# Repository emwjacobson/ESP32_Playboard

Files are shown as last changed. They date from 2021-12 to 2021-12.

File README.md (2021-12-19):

# ESP32 Playboard

I wasn't sure what to call this project other than the Playboard, so that's what it is. I got really into Espressif's [ESP-IDF](https://idf.espressif.com/) for developing on the ESP32, a dual core system running at 240MHz. The module that I chose has a 16MB SPI Flash chip and 8MB of PSRAM. 8MB and 4MB variants of the WROVER kit are also available, which can slightly reduce the price of it.

Using the LCSC BOM tool, a single board will cost ~$12, reducing to ~$8/board if making 100.

The Playboard includes the following sensors/devices:
- IR LED for Transmitting
- IR Receiver
- MicroSD Card Slot
- MPU-6050 IMU
- SHT30 Temperature/Humidity Sensor

In the PCB I added a small notch between the IR LED and the IR Receiver. This can be used to add a little divider to seperate them if simultaneous operation is required. Without a divider, the LED will be detected by the receiver.

## Schematic

Click to view full size PDF of schematic.
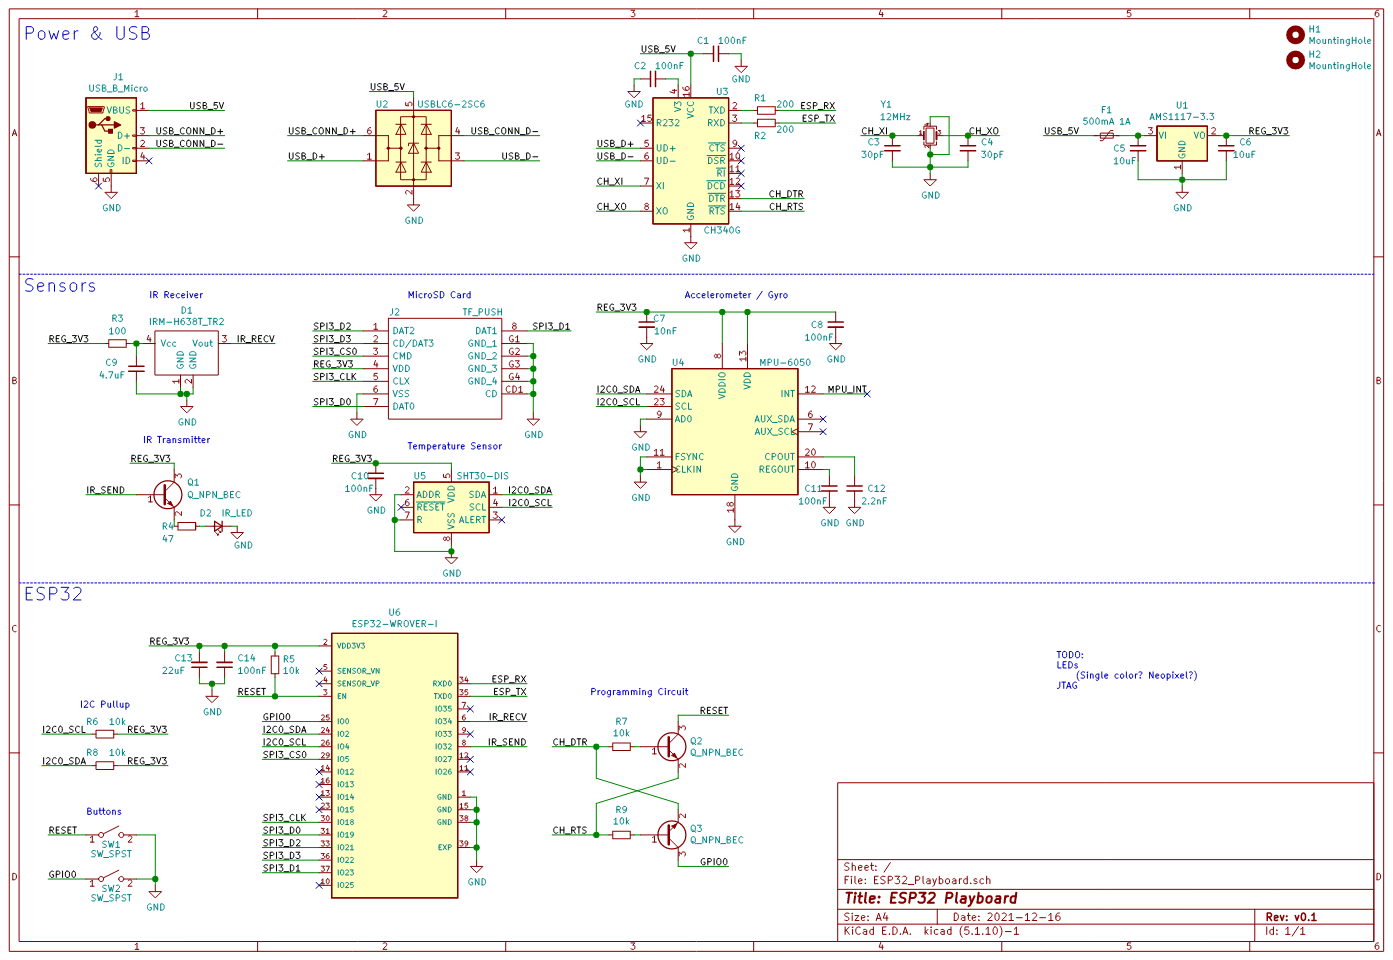
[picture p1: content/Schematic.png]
Schematic


## PCB

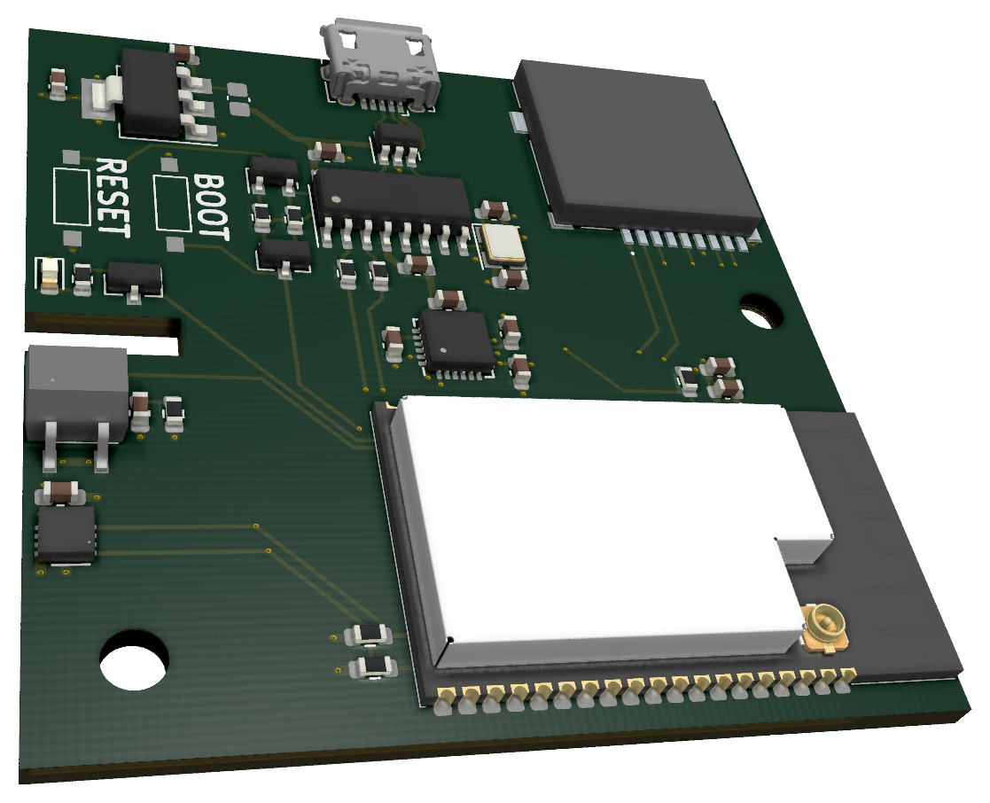
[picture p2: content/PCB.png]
PCB


## TODO

- JTAG Header
- Add some GPIO LEDs!
- Fill out the README more!

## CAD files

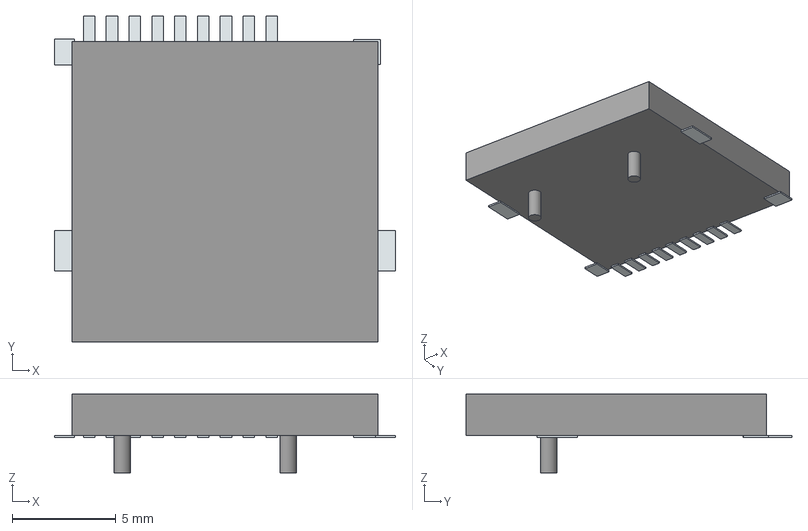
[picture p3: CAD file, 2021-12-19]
models/TF_PUSH.stp
16.5 x 15.7 x 3.80 mm
Pins
Lugs x 2

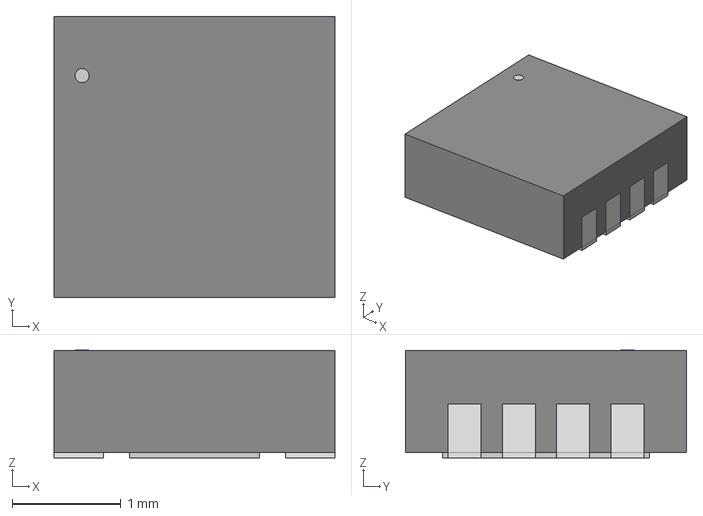
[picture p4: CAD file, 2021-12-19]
models/SHT3x-DIS_SEN.step
2.59 x 2.59 x 0.993 mm

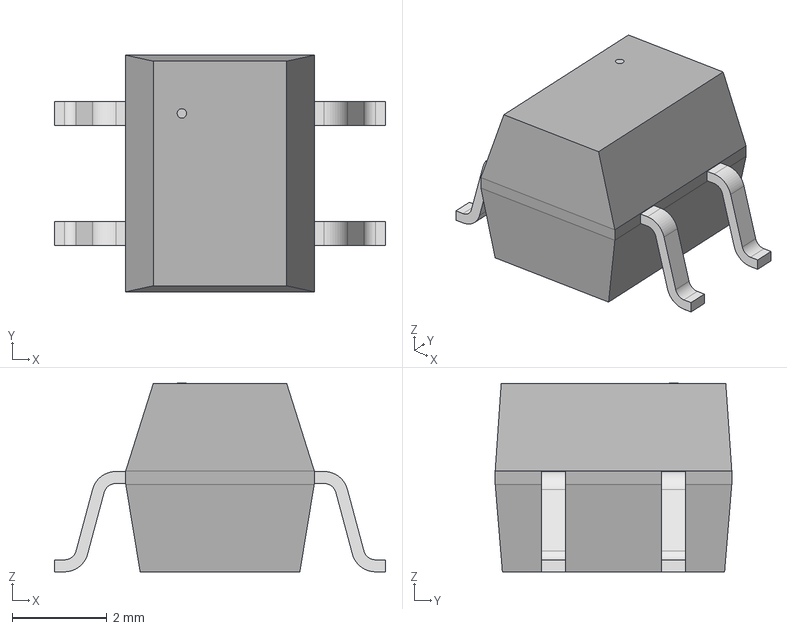
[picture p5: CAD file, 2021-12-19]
models/IRM-H638TTR2.step
7.00 x 5.00 x 3.99 mm

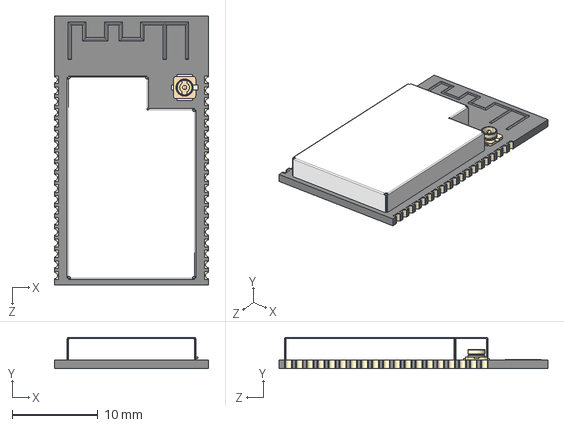
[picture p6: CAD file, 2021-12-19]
models/ESP32-WROVER-I.step
18.0 x 3.65 x 31.4 mm

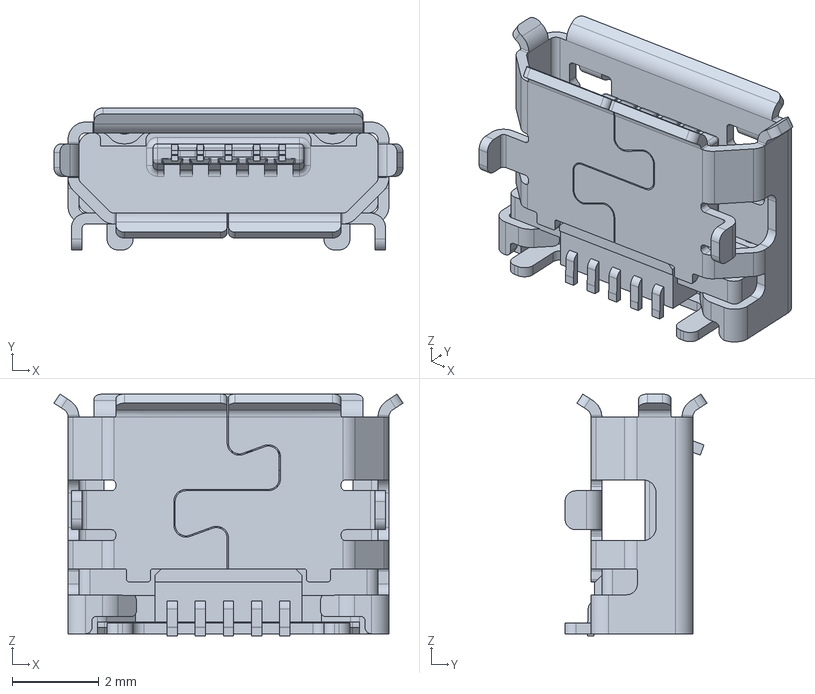
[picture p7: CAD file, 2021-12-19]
models/10118194-0001LF.STEP
8.05 x 3.27 x 5.58 mm

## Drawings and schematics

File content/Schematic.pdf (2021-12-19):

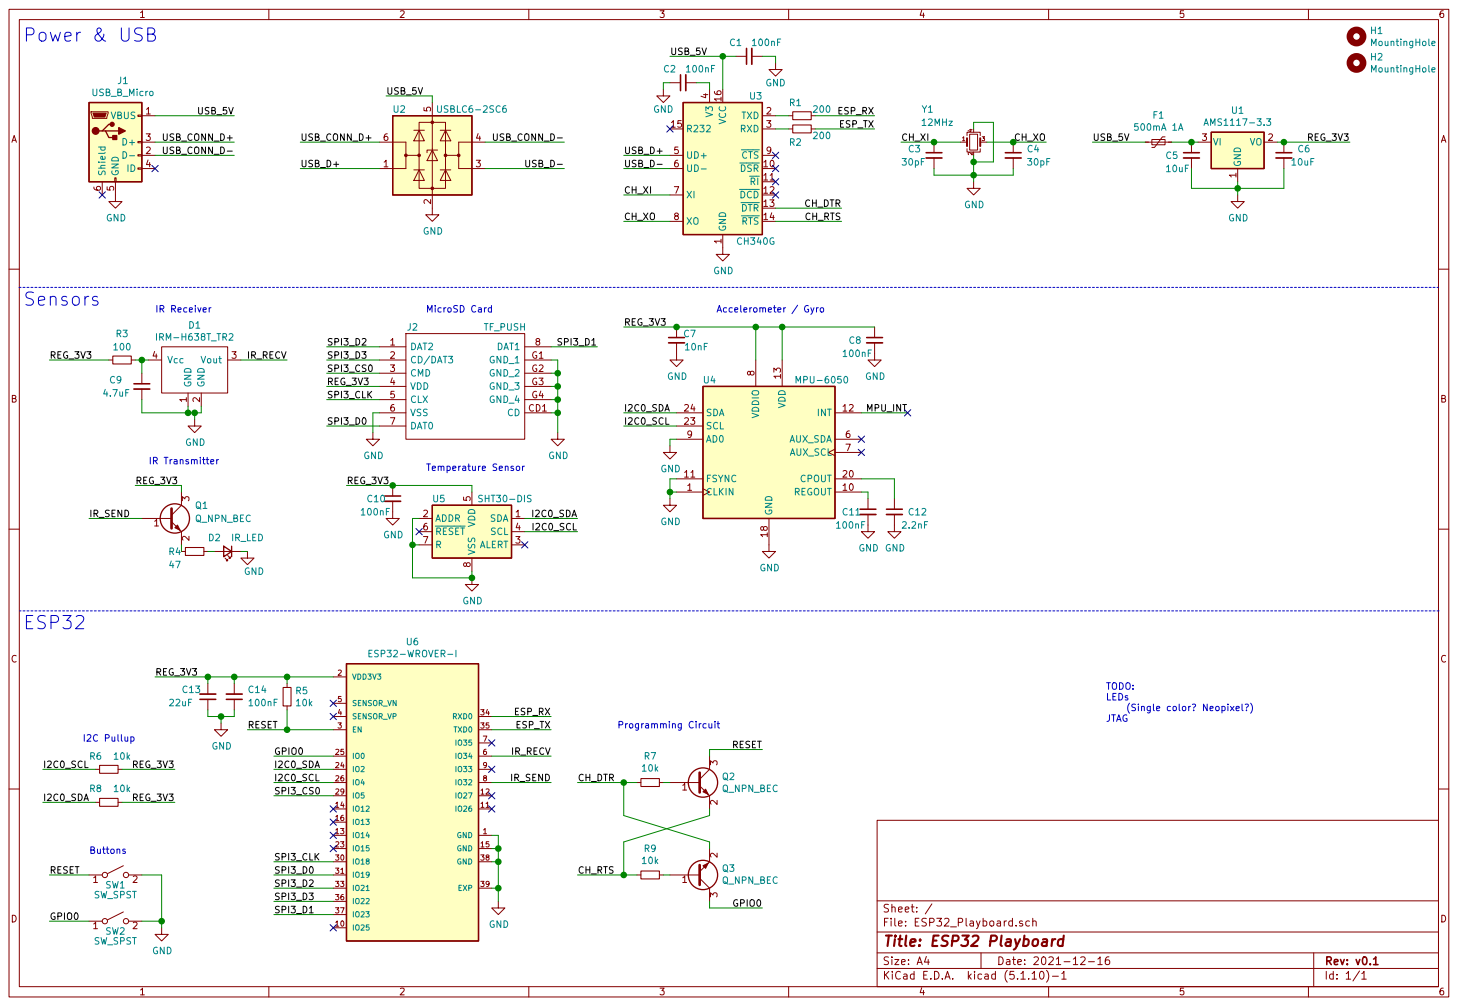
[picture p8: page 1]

1 DSR 10 RI 11 DCD 12 DTR 13 RTS 14 R232 15 VCC 16 TXD 2 RXD 3 V3

4 UD+ 5 UD- 6 XI 7 XO 8 CTS 9 U3 CH340G

1 VO 2 VI 3 U1 AMS1117-3.3 GND GND

(Single color? Neopixel?) JTAG

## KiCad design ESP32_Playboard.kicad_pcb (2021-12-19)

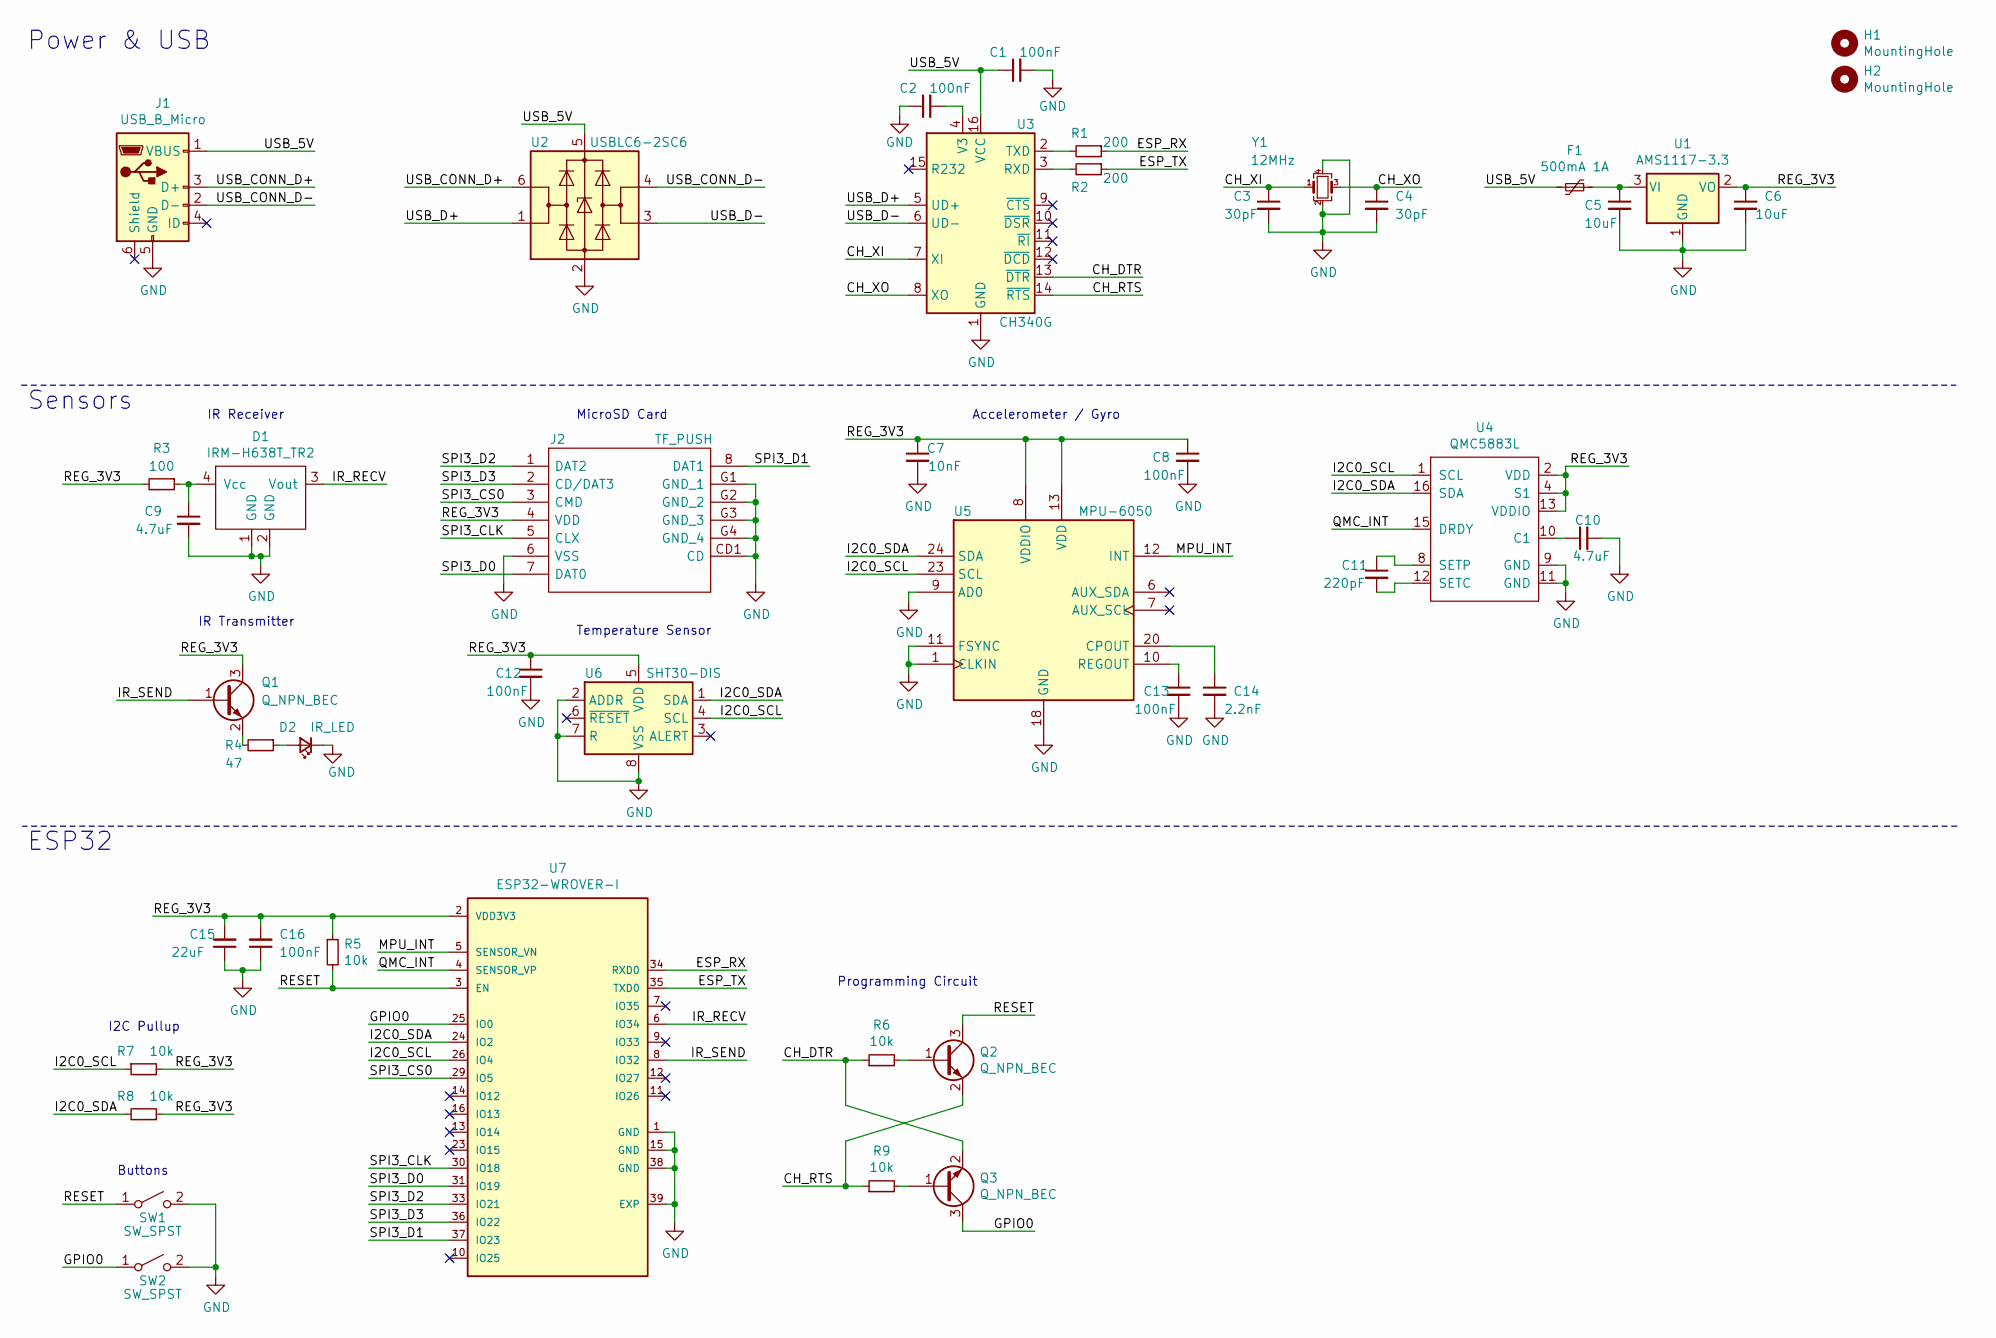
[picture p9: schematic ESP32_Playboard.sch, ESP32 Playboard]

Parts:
C1, C2, C8, C12, C13, C16: 100nF; C_0603_1608Metric; Manufacturer Part Number CC0603KRX7R9BB104; LCSC Part Number C14663
C3, C4: 30pF; C_0603_1608Metric; Manufacturer Part Number CC0603FRNPO9BN200; LCSC Part Number C326779
C5, C6: 10uF; C_0603_1608Metric; Manufacturer Part Number CL10A106KP8NNNC; LCSC Part Number C19702
C7: 10nF; C_0603_1608Metric; Manufacturer Part Number 0603B103K500NT; LCSC Part Number C57112
C9, C10: 4.7uF; C_0603_1608Metric; Manufacturer Part Number CL10A475KQ8NNNC; LCSC Part Number C8032
C11: 220pF; C_0603_1608Metric; Manufacturer Part Number CL10C221JB8NNNC; LCSC Part Number C27675
C14: 2.2nF; C_0603_1608Metric; Manufacturer Part Number 0603B222K500NT; LCSC Part Number C1604
C15: 22uF; C_0603_1608Metric; Manufacturer Part Number CL10A226MQ8NRNC; LCSC Part Number C59461
D1: IRM-H638T_TR2; LED-SMD-4; Manufacturer Part Number IRM-H638T/TR2; LCSC Part Number C91447
D2: IR_LED; LED_0603_1608Metric; Manufacturer Part Number MIR60363T; LCSC Part Number C50494
F1: 500mA 1A; Fuse_0805_2012Metric_Castellated; Manufacturer Part Number BSMD0805-050-24V; LCSC Part Number C910822
H1, H2: MountingHole; MountingHole_3.2mm_M3
J1: USB_B_Micro; USB_Micro-B_Amphenol_10118194_Horizontal; Manufacturer Part Number 10118194-0001LF; LCSC Part Number C132563
J2: TF_PUSH; TFPUSH; Manufacturer Part Number TF PUSH; LCSC Part Number C393941
Q1, Q2, Q3: Q_NPN_BEC; SOT-23; Manufacturer Part Number PMBT3904,215; LCSC Part Number C8667
R1, R2: 200; R_0603_1608Metric; Manufacturer Part Number 0603WAJ0201T5E; LCSC Part Number C25217
R3: 100; R_0603_1608Metric; Manufacturer Part Number RC0603FR-07100RL; LCSC Part Number C105588
R4: 47; R_0603_1608Metric; Manufacturer Part Number 0603WAJ0470T5E; LCSC Part Number C1211
R5, R6, R7, R8, R9: 10k; R_0603_1608Metric; Manufacturer Part Number 0603WAF1002T5E; LCSC Part Number C25804
SW1, SW2: SW_SPST; TS-1101-C-W; Manufacturer Part Number TS-1101-C-W; LCSC Part Number C318938
U1: AMS1117-3.3; SOT-223-3_TabPin2; Manufacturer Part Number AMS1117-3.3; LCSC Part Number C347222
U2: USBLC6-2SC6; SOT-23-6; Manufacturer Part Number USBLC6-2SC6; LCSC Part Number C2827654
U3: CH340G; SOIC-16_3.9x9.9mm_P1.27mm; Manufacturer Part Number CH340G; LCSC Part Number C14267
U4: QMC5883L; LGA-16_3x3mm_P0.5mm; Manufacturer Part Number QMC5883L; LCSC Part Number C976032
U5: MPU-6050; InvenSense_QFN-24_4x4mm_P0.5mm; Manufacturer Part Number MPU-6050; LCSC Part Number C24112
U6: SHT30-DIS; Sensirion_DFN-8-1EP_2.5x2.5mm_P0.5mm_EP1.1x1.7mm; Manufacturer Part Number SHT30-DIS-B2.5KS; LCSC Part Number C77361
U7: ESP32-WROVER-I; XCVR_ESP32-WROVER-I; Manufacturer Part Number ESP32-WROVER-IE(16MB); LCSC Part Number C701352
Y1: 12MHz; Crystal_SMD_3225-4Pin_3.2x2.5mm; Manufacturer Part Number X322512MSB4SI; LCSC Part Number C9002

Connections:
/CH_DTR: Q3.2 (E), R6.1, U3.13 (~DTR)
/CH_RTS: Q2.2 (E), R9.1, U3.14 (~RTS)
/CH_XI: C3.1, U3.7 (XI), Y1.1
/CH_XO: C4.1, U3.8 (XO), Y1.3
/ESP_RX: R1.1, U7.34 (RXD0)
/ESP_TX: R2.1, U7.35 (TXD0)
/GPIO0: Q3.3 (C), SW2.1 (A), U7.25 (IO0)
/I2C0_SCL: R7.1, U4.1 (SCL), U5.23 (SCL), U6.4 (SCL), U7.26 (IO4)
/I2C0_SDA: R8.2, U4.16 (SDA), U5.24 (SDA), U6.1 (SDA), U7.24 (IO2)
/IR_RECV: D1.3 (Vout), U7.6 (IO34)
/IR_SEND: Q1.1 (B), U7.8 (IO32)
/MPU_INT: U5.12 (INT), U7.5 (SENSOR_VN)
/QMC_INT: U4.15 (DRDY), U7.4 (SENSOR_VP)
/REG_3V3: C6.1, C7.1, C8.1, C12.1, C15.2, C16.2, J2.4 (VDD), Q1.3 (C), R3.2, R5.1, R7.2, R8.1, U1.2 (VO), U4.2 (VDD), U4.4 (S1), U4.13 (VDDIO), U5.8 (VDDIO), U5.13 (VDD), U6.5 (VDD), U7.2 (VDD3V3)
/RESET: Q2.3 (C), R5.2, SW1.1 (A), U7.3 (EN)
/SPI3_CLK: J2.5 (CLX), U7.30 (IO18)
/SPI3_CS0: J2.3 (CMD), U7.29 (IO5)
/SPI3_D0: J2.7 (DAT0), U7.31 (IO19)
/SPI3_D1: J2.8 (DAT1), U7.37 (IO23)
/SPI3_D2: J2.1 (DAT2), U7.33 (IO21)
/SPI3_D3: J2.2 (CD/DAT3), U7.36 (IO22)
/USB_5V: C1.1, F1.2, J1.1 (VBUS), U2.5 (VBUS), U3.16 (VCC)
/USB_CONN_D+: J1.3 (D+), U2.6 (I/O1)
/USB_CONN_D-: J1.2 (D-), U2.4 (I/O2)
/USB_D+: U2.1 (I/O1), U3.5 (UD+)
/USB_D-: U2.3 (I/O2), U3.6 (UD-)
GND: C1.2, C2.1, C3.2, C4.2, C5.2, C6.2, C7.2, C8.2, C9.2, C10.2, C12.2, C13.2, C14.2, C15.1, C16.1, D1.1 (GND), D1.2 (GND), D2.1 (K), J1.5 (GND), J2.6 (VSS), J2.CD1 (CD), J2.G1 (GND_1), J2.G2 (GND_2), J2.G3 (GND_3), J2.G4 (GND_4), SW1.2 (B), SW2.2 (B), U1.1 (GND), U2.2 (GND), U3.1 (GND), U4.9 (GND), U4.11 (GND), U5.1 (CLKIN), U5.9 (AD0), U5.11 (FSYNC), U5.18 (GND), U6.2 (ADDR), U6.7 (R), U6.8 (VSS), U6.9 (VSS), U7.1 (GND), U7.15 (GND), U7.38 (GND), U7.39 (EXP), Y1.2, Y1.4
unnamed: C2.2, U3.4 (V3)
unnamed: C5.1, F1.1, U1.3 (VI)
unnamed: C9.1, D1.4 (Vcc), R3.1
unnamed: C10.1, U4.10 (C1)
unnamed: C11.1, U4.8 (SETP)
unnamed: C11.2, U4.12 (SETC)
unnamed: C13.1, U5.10 (REGOUT)
unnamed: C14.1, U5.20 (CPOUT)
unnamed: D2.2 (A), R4.1
unnamed: Q1.2 (E), R4.2
unnamed: Q2.1 (B), R6.2
unnamed: Q3.1 (B), R9.2
unnamed: R1.2, U3.2 (TXD)
unnamed: R2.2, U3.3 (RXD)

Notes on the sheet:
Power & USB
ESP32
Sensors
IR Receiver
IR Transmitter
MicroSD Card
Temperature Sensor
Programming Circuit
I2C Pullup
Buttons
Accelerometer / Gyro

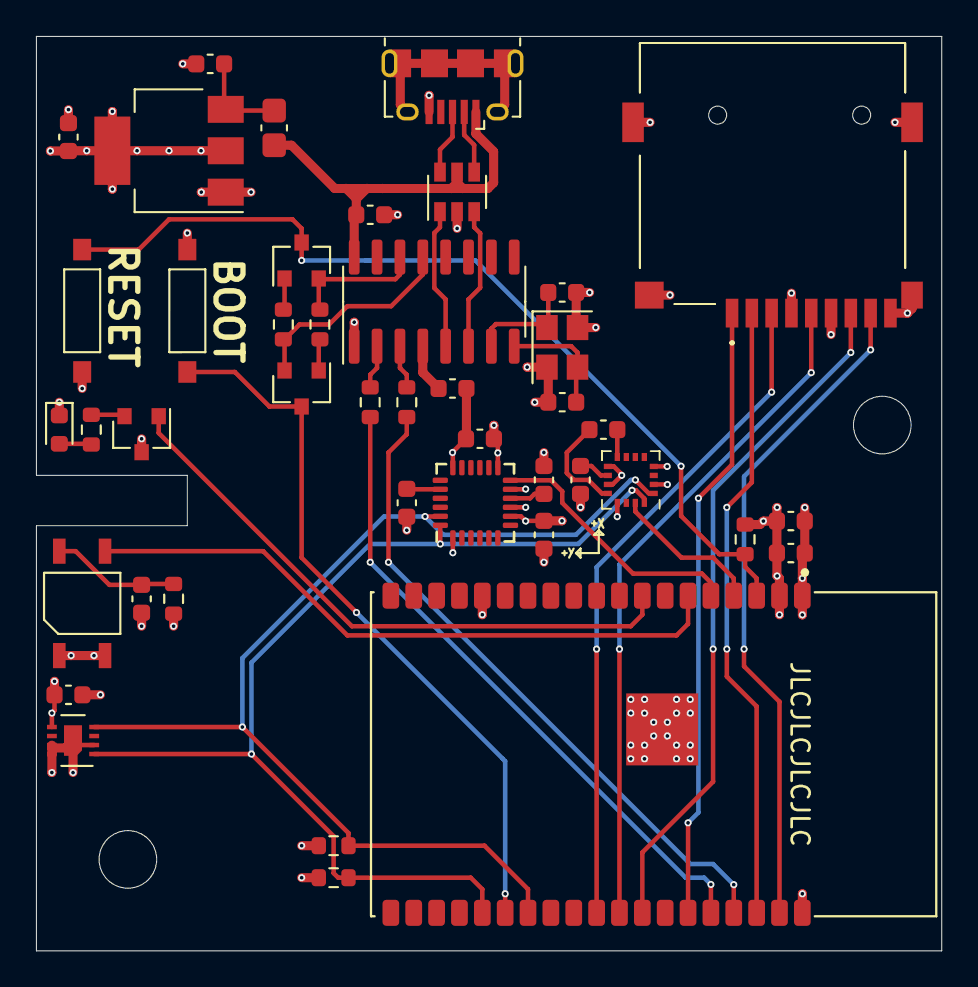
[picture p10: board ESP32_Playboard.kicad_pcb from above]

Board: 4 copper layers, 50.3 x 50.8 mm, 45 parts (0 on the bottom side), 41 nets.

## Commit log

2021-12-17 Added IR Transmitter & Receiver
    [ESP32_Playboard.sch]
2021-12-17 Finished adding SD Card, IMU, Temp sensor
    [ESP32_Playboard.sch, Sensors.sch]
2021-12-17 Started work on PCB
    [ESP32_Playboard.kicad_pcb, ESP32_Playboard.sch]
2021-12-17 Worked more on PCB layout
    [ESP32_Playboard.kicad_pcb, ESP32_Playboard.sch]
2021-12-18 Finished majority of PCB design
    [ESP32_Playboard.kicad_pcb]
2021-12-18 Finished PCB design
    [ESP32_Playboard.kicad_pcb, ESP32_Playboard.sch]
2021-12-18 Began work converting to esp module
    [ESP32-WROVER-I.step, ESP32_Playboard.sch]
2021-12-18 Updated schematic to include wrover module
    [ESP32_Playboard.sch]
2021-12-18 Finished basic PCB layout (no routing)
    [ESP32_Playboard.kicad_pcb, ESP32_Playboard.sch]
2021-12-18 Finished PCB layout
    [ESP32_Playboard.kicad_pcb, ESP32_Playboard.sch]
2021-12-19 Exported Gerber and started Readme
    [ESP32_Playboard-B_Cu.gbr, ESP32_Playboard-B_Mask.gbr, ESP32_Playboard-B_Paste.gbr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]
2021-12-19 Added 3d models to missing components
    [10118194-0001LF.STEP, ESP32_Playboard.kicad_pcb, IRM-H638TTR2.step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]
2021-12-19 Rearranged the schematic
    [ESP32_Playboard.sch]
2021-12-19 Updated schematic and pcb images
2021-12-19 Added magnetometer, attached interrupts, added silkscreen orientation
    [ESP32_Playboard.kicad_pcb, ESP32_Playboard.sch]
